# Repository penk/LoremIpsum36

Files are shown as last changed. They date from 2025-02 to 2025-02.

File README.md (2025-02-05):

## LoremIpsum36 - A minimal Gateron LP column staggered keyboard

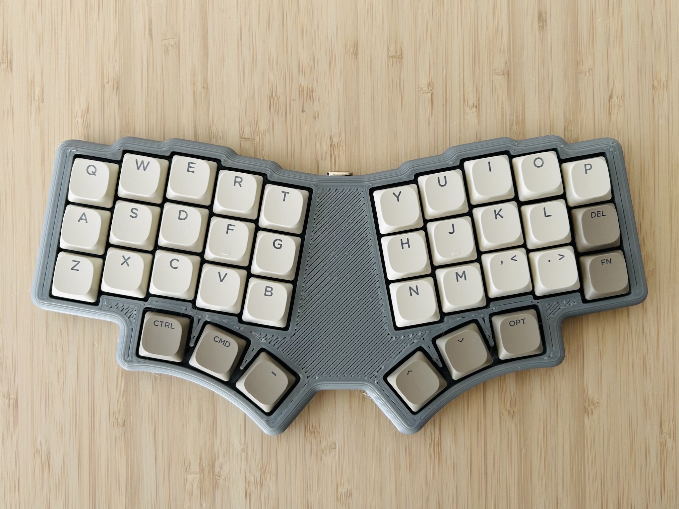
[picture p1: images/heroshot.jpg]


## Bill of Materials (BOM)

Quantity | Item
--- | ---
1 | RP2040-Zero
1 | LoremIpsum36 PCB
36 | Gateron LP switches and keycaps 
36 | KS-33 sockets
36 | 1N4148SOD-123 diodes
1 | LoremIpsum36 case
10 | M2×3 heat-set threaded inserts
10 | M2×12 countersunk screws

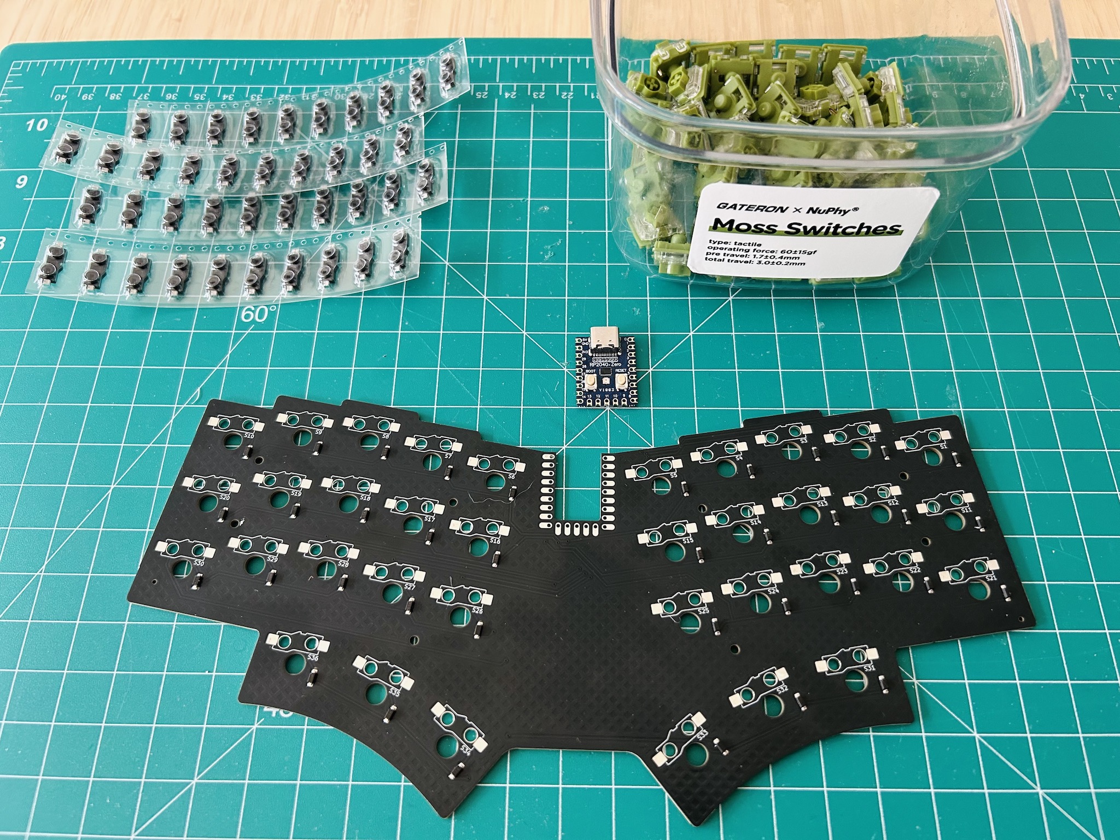
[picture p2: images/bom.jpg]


## Production Files

To place an order for the LoremIpsum36 PCB:

- Use the Gerber files available in the [production/](production/) folder.
- The [BOM](production/BOM.csv) and [CPL](production/CPL.csv) files can be used with a PCBA service -- especially if you prefer to avoid soldering small diodes.

All components (except the MCU) are soldered to the **back (bottom)** side of the board.

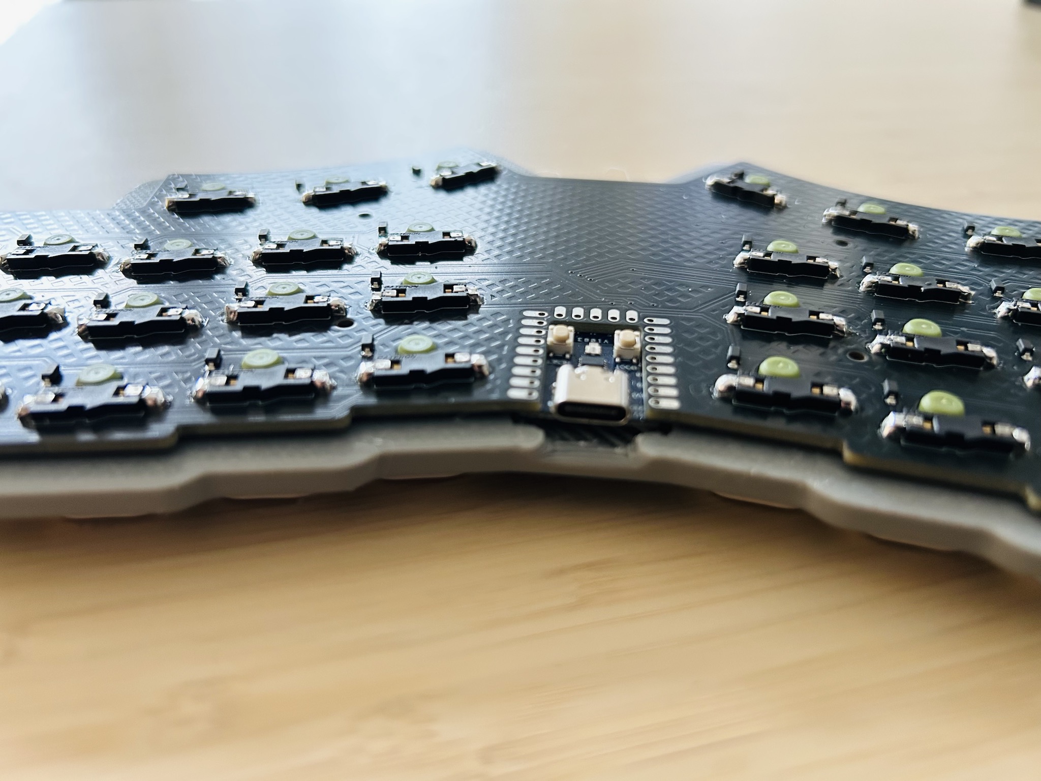
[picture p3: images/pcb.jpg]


> [!CAUTION]
> To maintain the low profile of the board, the MCU (RP2040-Zero) must be soldered **on the front (top)** side of the PCB, with its components facing **downwards**. 

The boot/reset button should face the bottom side of the keyboard. Double-check alignment before soldering to avoid incorrect placement: 

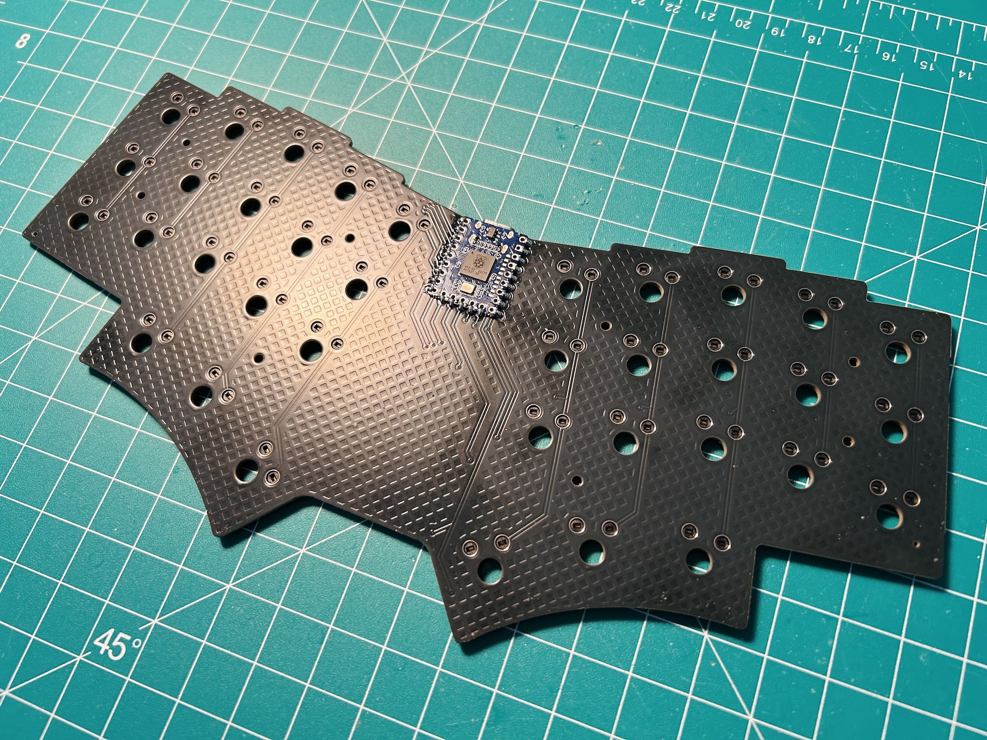
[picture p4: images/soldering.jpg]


The complete PCB design project is available in the [kicad/](kicad/) folder.

## 3D Printable Files

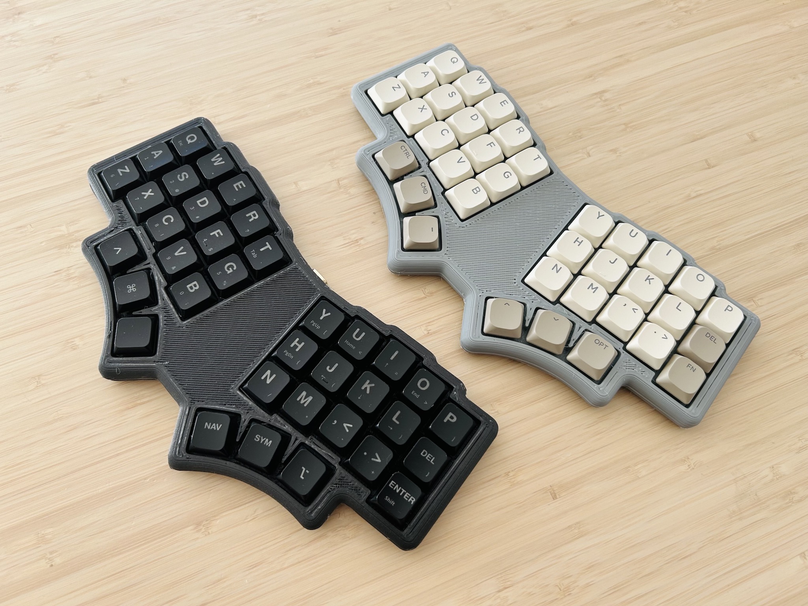
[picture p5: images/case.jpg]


Print the `loremipsum36-top` and `loremipsum36-bottom` case using the provided [STL files](case/), along with the threaded inserts and M2 screws.  

If you prefer to use the keyboard without a case, you will need to print the plate `loremipsum36-plate`, or laser cut a plate using the provided DXF file.

## Firmware

Precompiled VIA-enabled firmware:

- Flash `penk_loremipsum36_default.uf2` under [firmware/](firmware/) to the RP2040 MCU.
- Load the [via.json](firmware/QMK/keyboards/penk/loremipsum36/via.json) file in the `Design` tab for [VIA](https://usevia.app) configuration.

The QMK source is available under [firmware/QMK/keyboards/penk/loremipsum36](firmware/QMK/keyboards/penk/loremipsum36/).

### Default Keymaps 

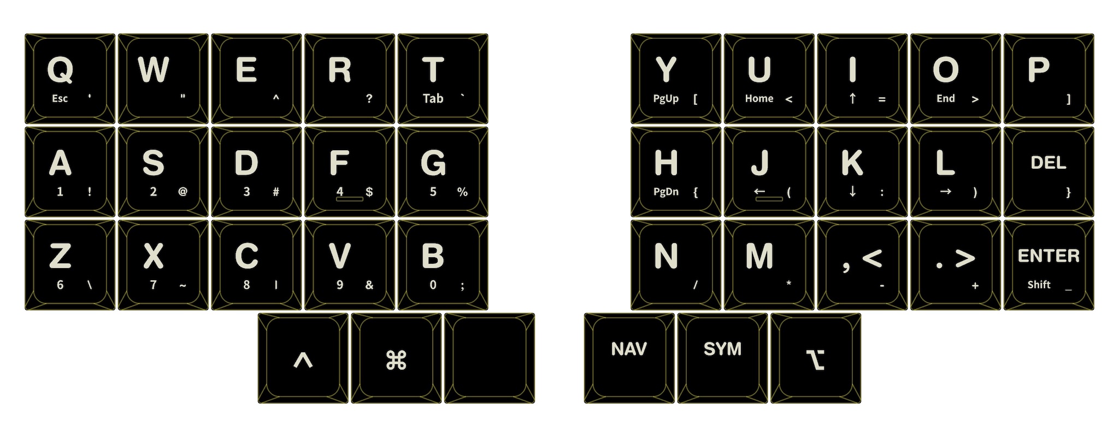
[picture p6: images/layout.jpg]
layout


The keymap is based on Rico's [rsta layout](https://github.com/rstacruz/my_qmk_keymaps/blob/main/preview.png), and the custom keycaps are made by FK Keycaps. 

You can order the same keycap set or customize yours at [https://fkcaps.com/custom/D7829J](https://fkcaps.com/custom/D7829J).

## Copyright and License
Copyright (c) 2025 Penk Chen. All rights reserved.

All files are licensed under the MIT license. For more information, see the [LICENSE](LICENSE).

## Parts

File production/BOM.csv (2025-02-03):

Designator | Footprint | Quantity | Value | LCSC Part #
D1, D10, D11, D12, D13, D14, D15, D16, D17, D18, D19, D2, D20, D21, D22, D23, D24, D25, D26, D27, D28, D29, D3, D30, D31, D32, D33, D34, D35, D36, D4, D5, D6, D7, D8, D9 | Diode_SOD-123 | 36 | Diode | C2972760
S1, S10, S11, S12, S13, S14, S15, S16, S17, S18, S19, S2, S20, S21, S22, S23, S24, S25, S26, S27, S28, S29, S3, S30, S31, S32, S33, S34, S35, S36, S4, S5, S6, S7, S8, S9 | SW_KS33_HS_KS-2P02B01-02_HS_1u | 36 | Keyswitch | C9900059694

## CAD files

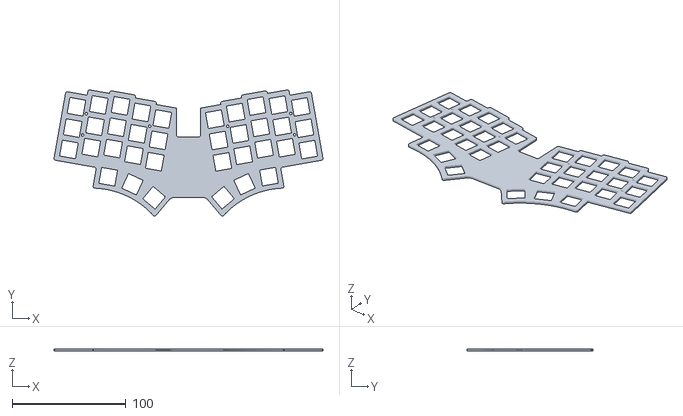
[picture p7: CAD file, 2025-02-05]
case/loremipsum36-plate.stl
236.5 x 111.0 x 1.80

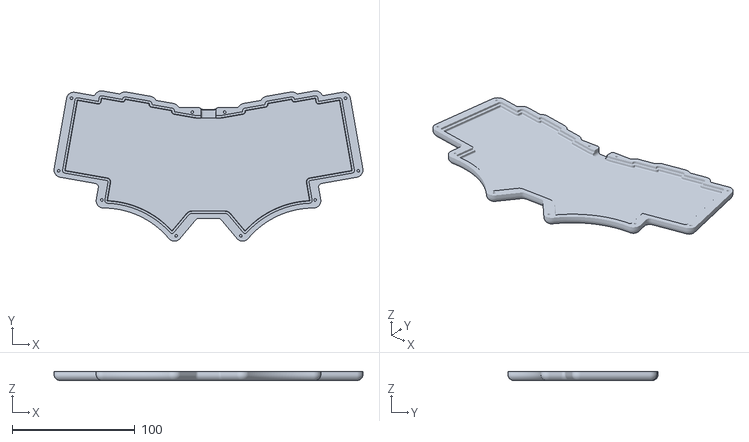
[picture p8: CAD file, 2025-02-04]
case/loremipsum36-bottom.stl
251.4 x 122.2 x 7.40

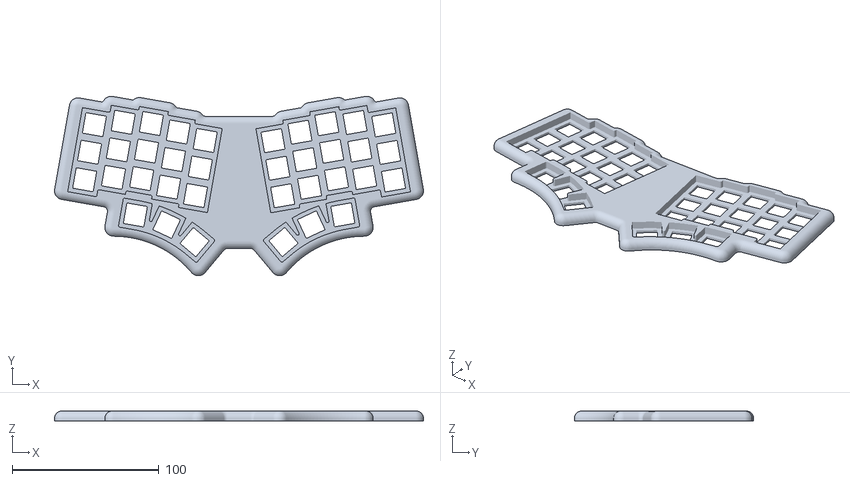
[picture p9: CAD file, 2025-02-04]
case/loremipsum36-top.stl
251.4 x 122.2 x 6.80

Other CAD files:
case/loremipsum36-plate.dxf

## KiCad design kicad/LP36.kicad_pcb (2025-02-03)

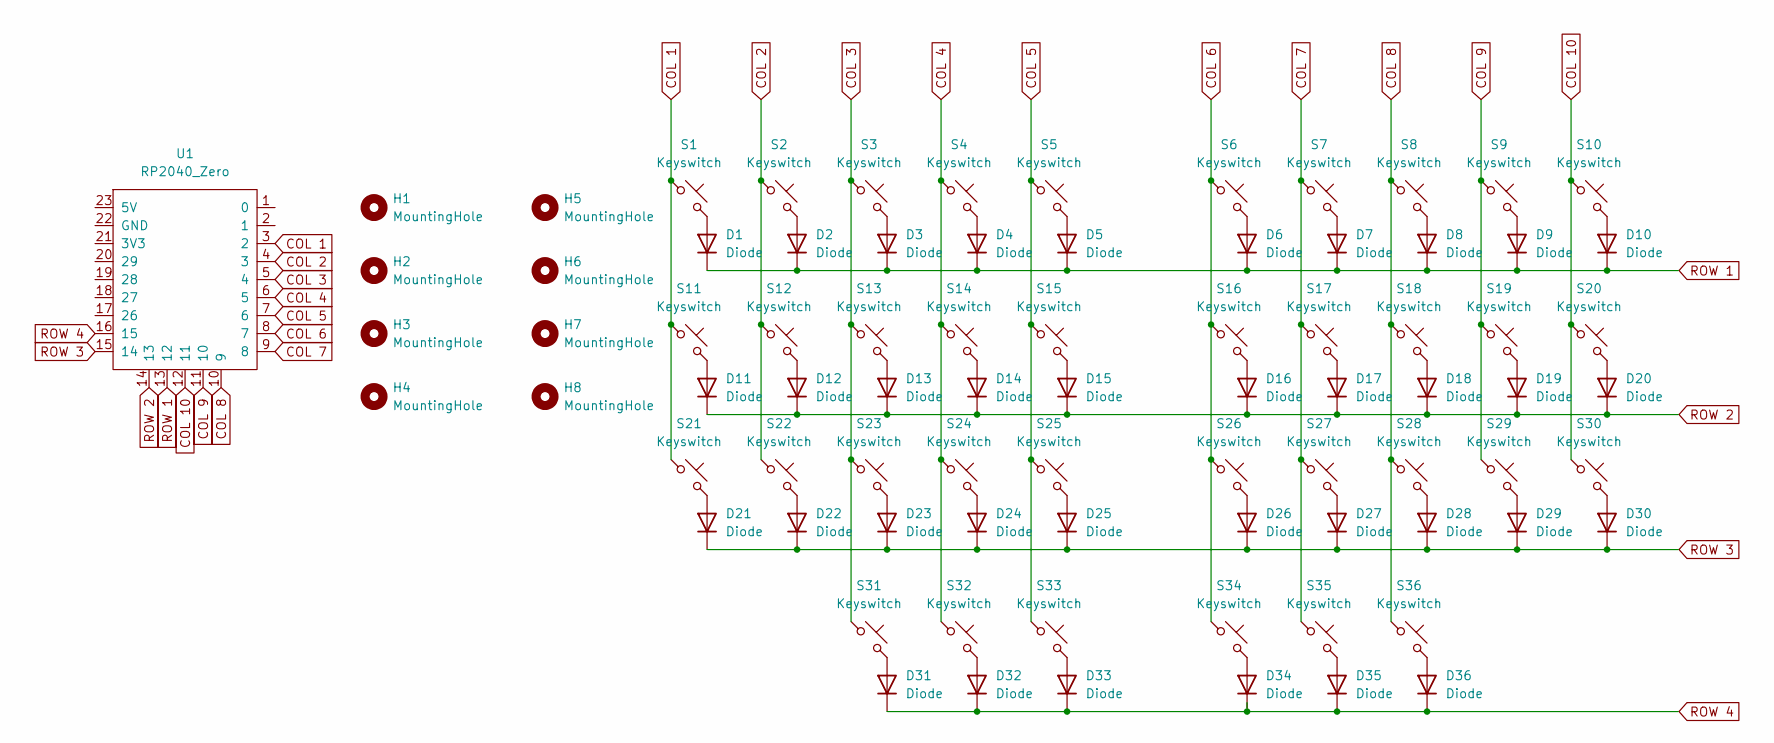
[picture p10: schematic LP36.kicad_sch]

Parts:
D1, D2, D3, D4, D5, D6, D7, D8, D9, D10, D11, D12, D13, D14, D15, D16, D17, D18, D19, D20, D21, D22, D23, D24, D25, D26, D27, D28, D29, D30, D31, D32, D33, D34, D35, D36: Diode; Diode_SOD-123
H1, H2, H3, H4, H5, H6, H7, H8: MountingHole; MountingHole_2.2mm_M2
S1, S2, S3, S4, S5, S6, S7, S8, S9, S10, S11, S12, S13, S14, S15, S16, S17, S18, S19, S20, S21, S22, S23, S24, S25, S26, S27, S28, S29, S30, S31, S32, S33, S34, S35, S36: Keyswitch; SW_KS33_HS_KS-2P02B01-02_HS_1u
U1: RP2040_Zero; RP2040_Zero_holes

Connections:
COL 1: S1.1, S11.1, S21.1, U1.3 (2)
COL 2: S2.1, S12.1, S22.1, U1.4 (3)
COL 3: S3.1, S13.1, S23.1, S31.1, U1.5 (4)
COL 4: S4.1, S14.1, S24.1, S32.1, U1.6 (5)
COL 5: S5.1, S15.1, S25.1, S33.1, U1.7 (6)
COL 6: S6.1, S16.1, S26.1, S34.1, U1.8 (7)
COL 7: S7.1, S17.1, S27.1, S35.1, U1.9 (8)
COL 8: S8.1, S18.1, S28.1, S36.1, U1.10 (9)
COL 9: S9.1, S19.1, S29.1, U1.11 (10)
COL 10: S10.1, S20.1, S30.1, U1.12 (11)
unnamed: D1.2 (A), S1.2
unnamed: D2.2 (A), S2.2
unnamed: D3.2 (A), S3.2
unnamed: D4.2 (A), S4.2
unnamed: D5.2 (A), S5.2
unnamed: D6.2 (A), S6.2
unnamed: D7.2 (A), S7.2
unnamed: D8.2 (A), S8.2
unnamed: D9.2 (A), S9.2
unnamed: D10.2 (A), S10.2
unnamed: D11.2 (A), S11.2
unnamed: D12.2 (A), S12.2
unnamed: D13.2 (A), S13.2
unnamed: D14.2 (A), S14.2
unnamed: D15.2 (A), S15.2
unnamed: D16.2 (A), S16.2
unnamed: D17.2 (A), S17.2
unnamed: D18.2 (A), S18.2
unnamed: D19.2 (A), S19.2
unnamed: D20.2 (A), S20.2
unnamed: D21.2 (A), S21.2
unnamed: D22.2 (A), S22.2
unnamed: D23.2 (A), S23.2
unnamed: D24.2 (A), S24.2
unnamed: D25.2 (A), S25.2
unnamed: D26.2 (A), S26.2
unnamed: D27.2 (A), S27.2
unnamed: D28.2 (A), S28.2
unnamed: D29.2 (A), S29.2
unnamed: D30.2 (A), S30.2
unnamed: D31.2 (A), S31.2
unnamed: D32.2 (A), S32.2
unnamed: D33.2 (A), S33.2
unnamed: D34.2 (A), S34.2
unnamed: D35.2 (A), S35.2
unnamed: D36.2 (A), S36.2
ROW 1: D1.1 (K), D2.1 (K), D3.1 (K), D4.1 (K), D5.1 (K), D6.1 (K), D7.1 (K), D8.1 (K), D9.1 (K), D10.1 (K), U1.13 (12)
ROW 2: D11.1 (K), D12.1 (K), D13.1 (K), D14.1 (K), D15.1 (K), D16.1 (K), D17.1 (K), D18.1 (K), D19.1 (K), D20.1 (K), U1.14 (13)
ROW 3: D21.1 (K), D22.1 (K), D23.1 (K), D24.1 (K), D25.1 (K), D26.1 (K), D27.1 (K), D28.1 (K), D29.1 (K), D30.1 (K), U1.15 (14)
ROW 4: D31.1 (K), D32.1 (K), D33.1 (K), D34.1 (K), D35.1 (K), D36.1 (K), U1.16 (15)

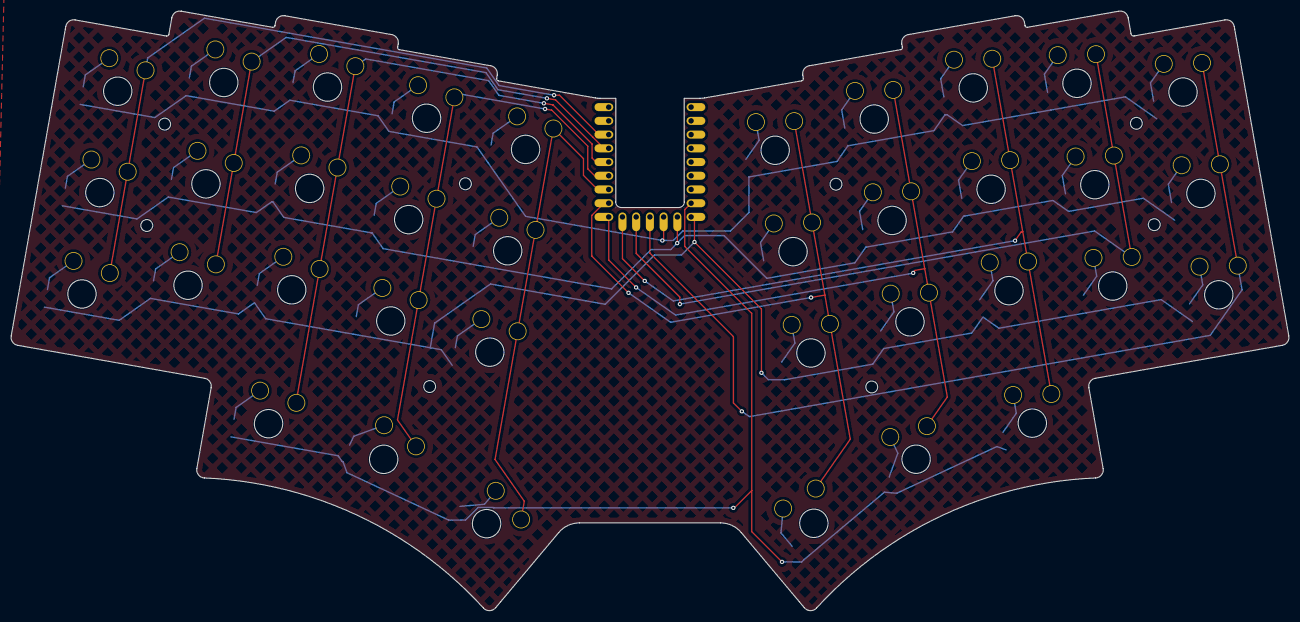
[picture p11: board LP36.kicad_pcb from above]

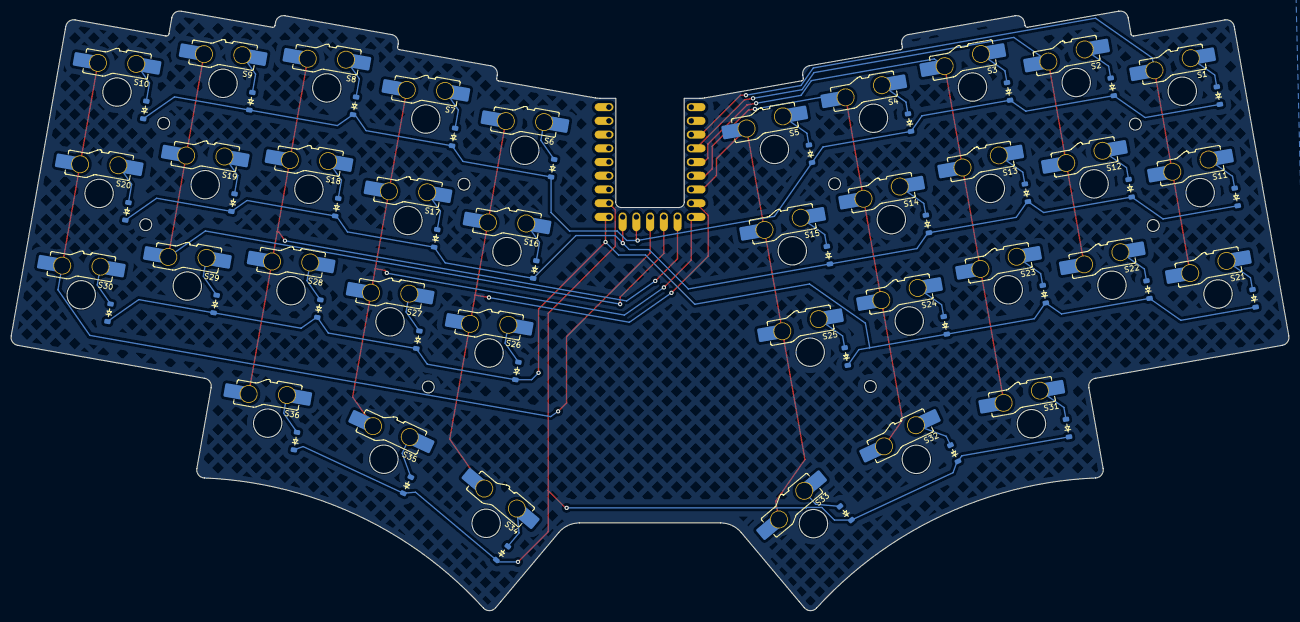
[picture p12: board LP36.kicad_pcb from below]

Board: 2 copper layers, 236.5 x 111.0 mm, 81 parts (73 on the bottom side), 50 nets.

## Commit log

2025-02-04 Add STEP and DXF for the case
    [loremipsum36-bottom.stl, loremipsum36-plate.dxf, loremipsum36-top.stl]
2025-02-05 Add plate
    [loremipsum36-plate.stl]
